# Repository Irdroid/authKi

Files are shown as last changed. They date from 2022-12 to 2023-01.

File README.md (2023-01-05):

# Open Source Crypto Authentication USB Dongle
<p align="center" width="55%">
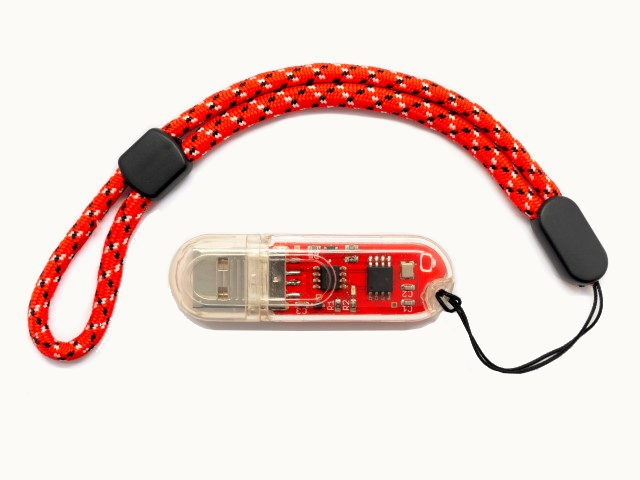
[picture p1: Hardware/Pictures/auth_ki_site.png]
     
</p>

Irdroid authKi is a Open Source crypto Authentication USB Dongle (Open source Hardware ID - BG000091), with built-in hardware support for Asymmetric Sign, Verify, Key Agreement for ECDSA - Elliptic curve digital signature algorithm, ECDH - Elliptic Curve Diffie-Hellman and NIST Standard P256 Elliptic Curve Support,  thanks to the built-in Cryptographic Co-Processor with Secure Hardware-Based Key Storage - ATECC608B by Microchip.

USB 2.0 Interface (and optional USB-C) to the host system with built-in drivers for GNU Linux. The authKi is targeted for use in GNU Linux, the ATECC608B crypto element inside the authKi can be accessed via libusb in MS Windows and Mac OS (Still work in progress). The device will show-up on the host system as a I2C sysfs entry, which is then used by the Microchip’s cryptoauthlib for communication with the authKi dongle.

## Hardware support for:

- Asymmetric Sign, Verify, Key Agreement:
- ECDSA: FIPS186-3 Elliptic Curve Digital Signature
- ECDH: FIPS SP800-56A Elliptic Curve Diffie-Hellman
- NIST Standard P256 Elliptic Curve Support

## Symmetric Algorithms:

- SHA-256 & HMAC Hash including off-chip context save/restore
- AES-128: Encrypt/Decrypt, Galois Field Multiply for GCM

## Networking Key Management Support:

- Turnkey PRF/HKDF calculation for TLS 1.2 & 1.3
- Ephemeral key generation and key agreement in SRAM
- Small message encryption with keys entirely protected

## Software Support:

- Microchip’s Cryptoauthlib ( provides API and examples for interfacing with the authKi
- Eclet - a commandline tool to sign verify export public keys
- Other examples in the Irdroid’s authKi Github repository

## Example use:

- SSH authentication with a remote system via ECDSA keypairs ( your private key never leaves the hardware secure element e.g the AuthKi)
- ECDSA elliptic curve authentication with git / GitHub ( your private key never leaves the hardware secure element e.g the AuthKi)
- Digital Signature and Verification of files via Ellliptic Curve Algorithms (ECDSA/ECDSH)
- Developing Secure Crypto Wallets for Bitcoin / Ethereum
- Experimenting with the Microchip’s Cryptoauthlib for interfacing with the device.

## Where to start?

### 1. Clone this repository: 
```javascript
git clone --recurse-submodules https://github.com/Irdroid/authKi.git
```
This will checkout the repo and all submodules. You can then compile and install the cryptoauthlib library localted in /Software/Cryptoauthlib/
**You can also download a pre-built release package from the "releases" section above**.
    
### 2.  Install OpenSC:
```javascript
sudo apt install opensc
```
Check if the sysfs /dev/i2c-x entry for the device is created (After you plug the authKi to your system issue dmesg, and see if the /dev/i2c-x is assigned), if not then you may need to issue:

```
sudo modprobe i2c-dev
```
The above will load the kernel module for i2c dev sysfs

### 4. Set **udev rules** 
(If you are compiling from source | **You can skip this step if you are installing a prebuilt cryptoauthlib package from the releases section above**), so that the authKi will always get the same i2c interface number as a sysfs entry 
    - Create a file in /etc/udev/rules.d/11-tiny.rules with the content : 
```javascript 
   ACTION=="add|change", SUBSYSTEM=="i2c-dev", ATTRS{idVendor}=="0403", ATTRS{idProduct}=="c631", SYMLINK+="i2c-20"
```
### 5. Create / Edit /var/lib/cryptoauthlib/0.conf
Add the following content ( If you are compiling / installing from source)
```javascript 

# Reserved Configuration for a device
# The objects in this file will be created and marked as undeletable
# These are processed in order. Configuration parameters must be comma
# delimited and may not contain spaces

# Set a label for this slot (optional) - will default to <slot>ABC so
# 0.conf will have a default label 00ABC
label = 00ABC

# Configure the device interface for an enabled HAL
# hid,i2c,<address>
# i2c,<address>,<bus>
# spi,<select_line>,<baud>
interface = i2c,6C,20

# Configure the device type - base part number (optional)
device = ATECC608B-TFLXTLS

#Configure open slots for additional pkcs11 objects (optional)
#freeslots = 1,2,3
freeslots = 2,3,4,5
# Manually configure keys into device locations (slots/handles)

# Slot 0 is the primary private key
object = private,device,0
#object = private,device,0
# Slot 15 is a public key
#object = public,root,15
```
### 6. Configure SSH:
Edit /home/your_user/.ssh/config and add:
```javascript 
PKCS11Provider /usr/lib/libcryptoauth.so
```
The above will configure the cryptoauthlib as a PKCS11 Provider for All SSH connections. To configure the use of the library and the authki for specific connection add the following (for example for GitHub authentication in ./ssh/config)

```javascript 
Host github.com
 PKCS11Provider /usr/lib/libcryptoauth.so
 Port 22
 User youruser
```
This way if you have multipl authentication dongles, and/or smartcards you can specify which connection will use the relevant authentication key/smartcard

### 7. Export the ECDSA Public key from the authKi
```javascript
ssh-keygen -D /usr/lib/libcryptoauth.so
```
### 8. Use the authKi for SSH Authentication / Github GIT+SSH
The above command will print your public ECDSA key in the console, the key is suitable for usage in a remote server authorized_keys file or with Github
After putting the public key into a remote system , you can ssh into it, while your authKi is inserted in your computer.

### 9 Configuring authKi for use with the Eclet

1. Compile and install the Ecltet, the source is located in /Software/Eclet

#### random
```bash
eclet random
62F95589AC76855A8F9204C9C6B8B85F06E6477D17C3888266AEE8E1CBD65319
```
#### serial-num
```bash
eclet serial-num
0123XXXXXXXXXXXXEE
```
X's indicate the unique serial number.

#### get-pub
```bash
eclet get-pub
04EED1CB629CF87F8BF6419986F990B92EA3DFA14CDAF70EB3E8DA8F9C9504DBC5B040D6480E88F895E9E1D4477970329B060450C80E1816EFED7B0FA49868CAEB
```
One can get the public key at any time calling the command get-pub. In case the public key of a specific slot has to be called use the parameter -k.

```bash
eclet get-pub -k 0
04EED1CB629CF87F8BF6419986F990B92EA3DFA14CDAF70EB3E8DA8F9C9504DBC5B040D6480E88F895E9E1D4477970329B060450C80E1816EFED7B0FA49868CAEB
```

#### sign
```bash
eclet sign -f ChangeLog
3BAEB5705D8765B34B389F1768BAC783FCA786AB64A760D10DD133C86E5892A7A790E424C8E1540551C99FBE4F9F531B504A6004F08F3E0D4E42E96BBDE5C179
```

Performs an ECDSA signature. Data can be specified as a file with the `-f` option or passed via `stdin`. The data will be SHA256 hashed prior to signing. The result is the signature in the format: R + S.

#### verify
```bash
eclet verify -f ChangeLog --signature C650D1A30194AD68F60F40C321FB084F6177BEDAC74D0F0C276ED35B00249AC8CF3E96FB7AB14AA48223FBA2E5DD9BCAE232BF963755C42F8FD9BD77FC145D41 --public-key 049B4A517704E16F3C99C6973E29F882EAF840DCD125C725C9552148A74349EB77BECB37AA2DB8056BAF0E236F6DCFEC2C5A9A0F23CEFD8A9DC1F4693718E725D2
```

Verifies an ECDSA signature using the device. You specify the data (which will be SHA256 hashed), the signature (R+S), and the public key (0x04+X+Y). Returns a `0` exit code on success.

#### offline-verify-sign
```bash
eclet offline-verify-sign -f ChangeLog --signature C650D1A30194AD68F60F40C321FB084F6177BEDAC74D0F0C276ED35B00249AC8CF3E96FB7AB14AA48223FBA2E5DD9BCAE232BF963755C42F8FD9BD77FC145D41 --public-key 049B4A517704E16F3C99C6973E29F882EAF840DCD125C725C9552148A74349EB77BECB37AA2DB8056BAF0E236F6DCFEC2C5A9A0F23CEFD8A9DC1F4693718E725D2
```
#### 10. There are other examples in the cryptoauthlib directory for other functionalities such as AES128 enclode/decode, SHA-256 tests and examples and more. 

### authKi unit's are available for purchase from Tindie - Click on the Tindie Logo below to see product details and pricing
<p align="center" width="30%">
<a href="https://www.tindie.com/products/irdroid/authki-crypto-authentication-dongle/">authKi ot Tindie</a>
</p>

The authKi repository and and the authKi website were pushed to GitHub, by using the Irdroid's authKi ECDSA Keypair

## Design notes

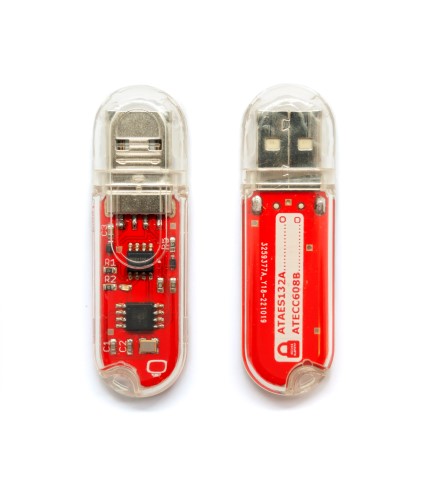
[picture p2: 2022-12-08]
Hardware/Pictures/PB170094-1-3 (Small).jpg

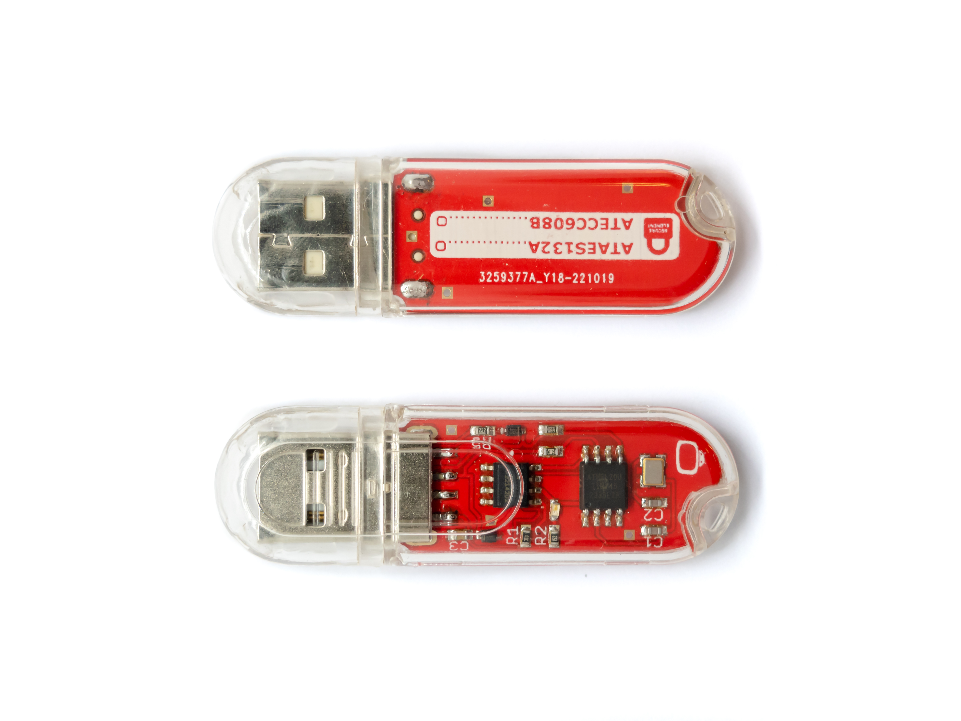
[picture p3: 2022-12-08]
Hardware/Pictures/Hi-Res/PB170094-3.jpg

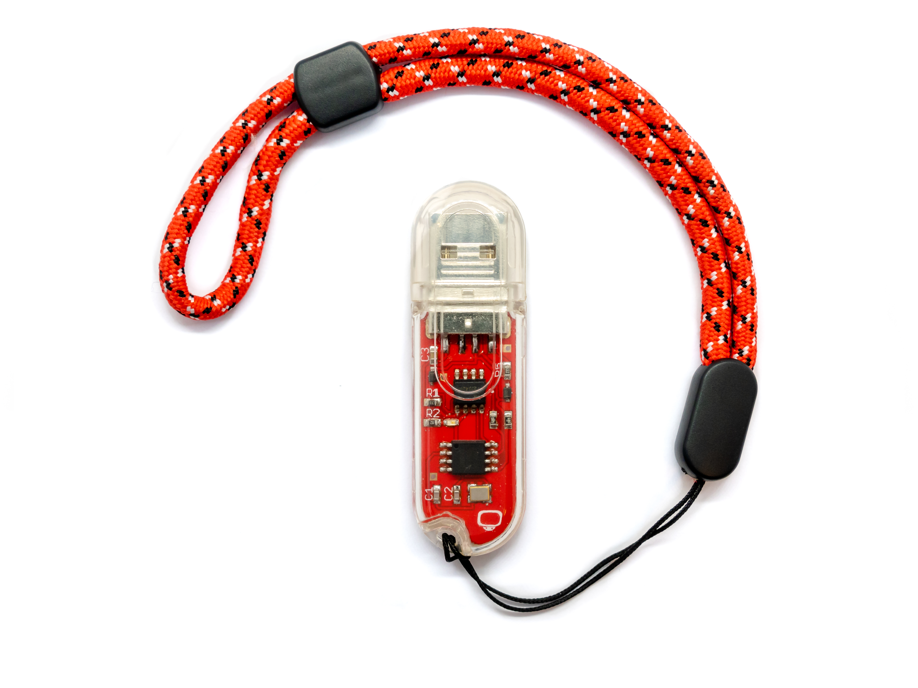
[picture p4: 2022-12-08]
Hardware/Pictures/Hi-Res/PB170083-2.jpg

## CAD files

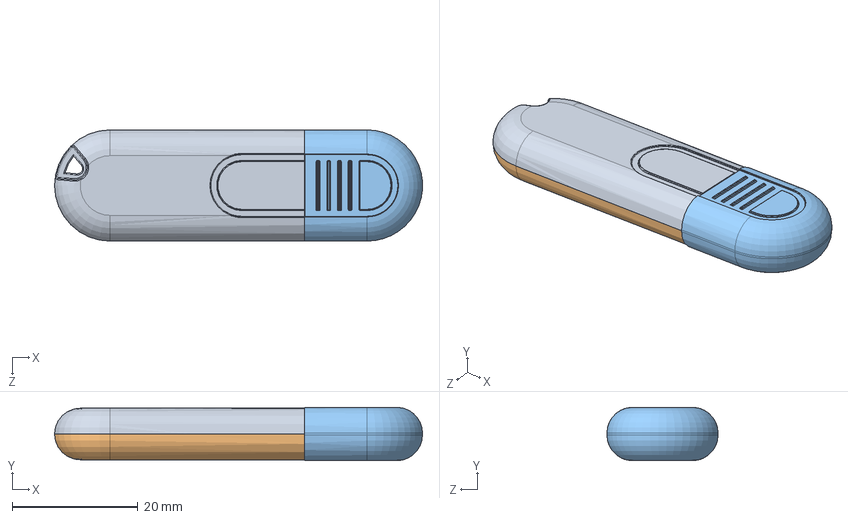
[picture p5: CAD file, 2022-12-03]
Hardware/Enclosure/3D Model/Сборка корпуса.SLDASM
58.6 x 8.50 x 17.7 mm
Верх
Низ
Колпачек

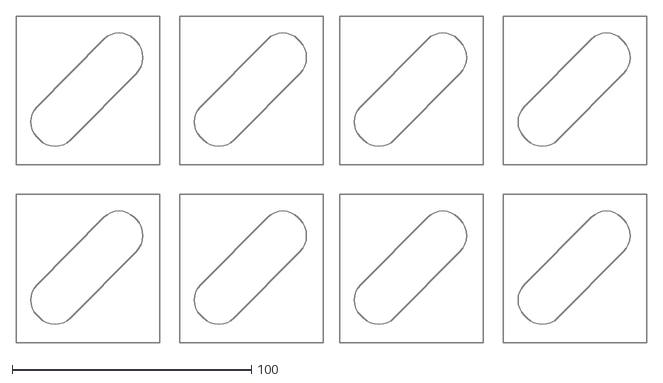
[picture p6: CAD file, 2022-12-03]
Hardware/Packing Box/DXF/boxpouter_grouped_with_opening.dxf
263.6 x 136.4

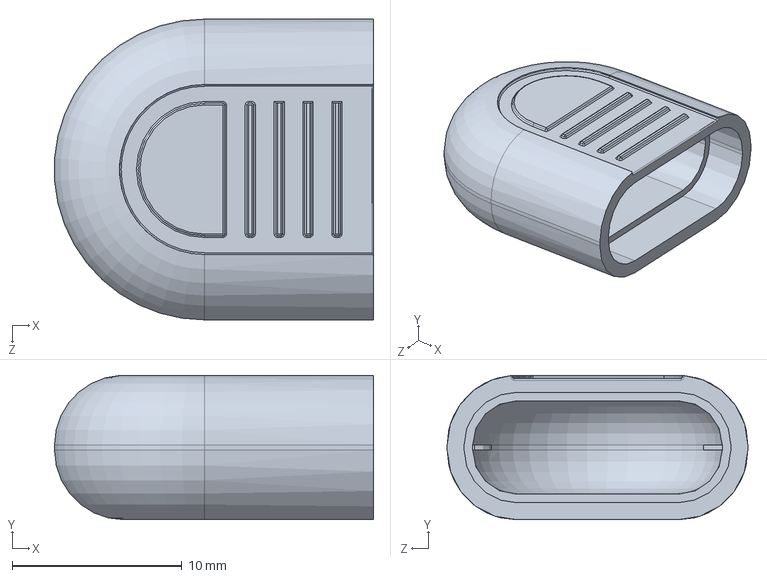
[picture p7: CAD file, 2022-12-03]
Hardware/Enclosure/3D Model/Колпачек.SLDPRT
18.8 x 8.50 x 17.7 mm

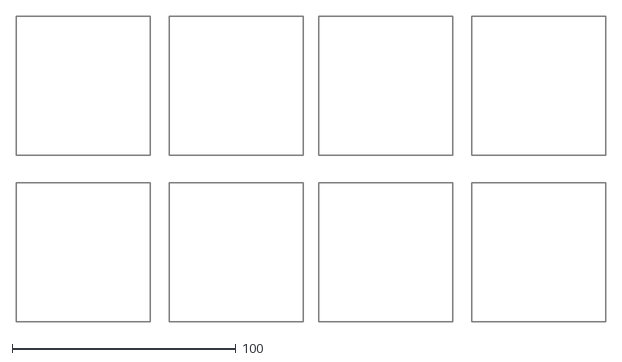
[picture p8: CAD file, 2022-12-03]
Hardware/Packing Box/DXF/boxpouter_grouped.dxf
263.6 x 136.4

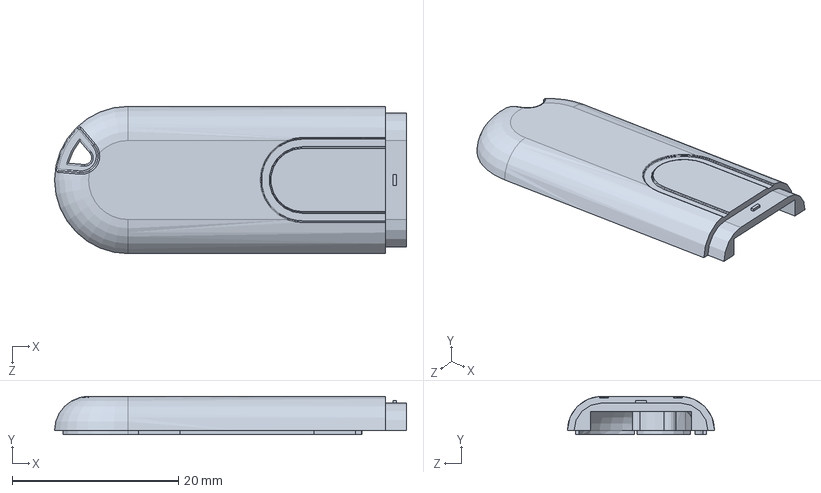
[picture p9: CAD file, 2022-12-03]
Hardware/Enclosure/3D Model/Верх.SLDPRT
42.3 x 4.60 x 17.7 mm

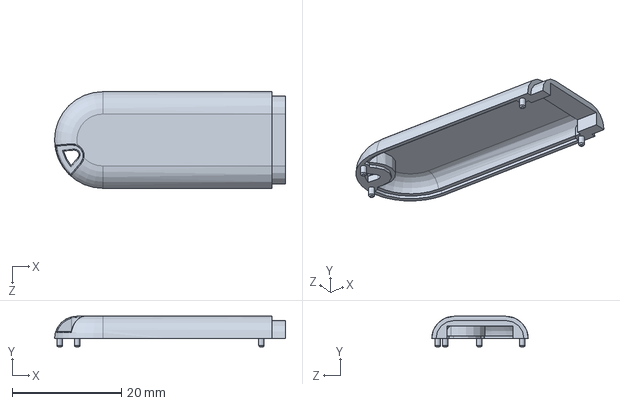
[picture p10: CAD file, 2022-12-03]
Hardware/Enclosure/3D Model/Низ.SLDPRT
42.3 x 5.60 x 17.7 mm

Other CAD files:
Hardware/Enclosure/3D Model/small plastic instrument enclosure usb stick junction housing abs material pcb enclosure.STEP

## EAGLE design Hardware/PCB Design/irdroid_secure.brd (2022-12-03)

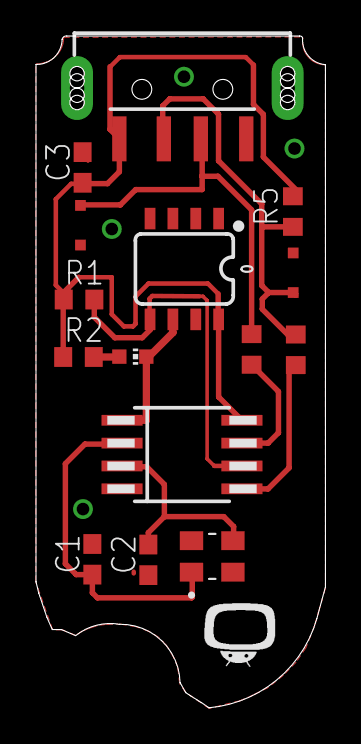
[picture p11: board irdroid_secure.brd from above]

Board: 2 copper layers, 16.1 x 37.3 mm, 16 parts (0 on the bottom side), 11 nets.

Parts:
0: Crypto; SO08
C1, C2, C3: C0603
D1, D2: SOD323-R
J1: USB_A_SMT_MALE; USB-A-SMT-MALE
LED1: CHIP-LED0603
MC: ATTINY45V-10S; SOIC8_EIAJ_208MIL
R1, R2, R3, R4, R5: R0603
U$2: IRDROIDLOGO
Y1: ABM8-16.000MHZ-B2-T; XTAL_ABM8-16.000MHZ-B2-T

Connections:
GND: 0.4, C1.2, C2.1, C3.2, D1.A, D2.A, J1.GND1, J1.SHLD1, J1.SHLD2, MC.4, Y1.2, Y1.4
unnamed: C1.1, MC.2, Y1.1
unnamed: C2.2, MC.3, Y1.3
unnamed: 0.5, MC.6, R1.2
unnamed: 0.6, LED1.C, MC.1
unnamed: MC.5, R3.2
unnamed: MC.7, R4.2
unnamed: D2.C, J1.D-1, R3.1, R5.1
unnamed: LED1.A, R2.2
unnamed: D1.C, J1.D+1, R4.1
VCC: 0.8, C3.1, J1.VBUS1, MC.8, R1.1, R2.1, R5.2

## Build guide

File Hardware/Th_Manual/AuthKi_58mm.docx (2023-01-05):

Start Here:

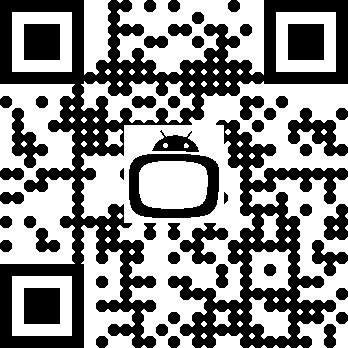
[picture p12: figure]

https://github.com/irdroid/authKi

AuthKi is Open source software and open source hardware, more information at:

https://certification.oshwa.org/bg000091.html

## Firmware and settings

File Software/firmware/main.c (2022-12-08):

/* Name: main.c
 * Project: i2c-tiny-usb
 * Author: Till Harbaum
 * Tabsize: 4
 * Copyright: (c) 2005 by Till Harbaum <till@harbaum.org>
 * License: GPL
 * This Revision: $Id: main.c,v 1.9 2007/06/07 13:53:47 harbaum Exp $
 *
 * $Log: main.c,v $
 * Revision 1.9  2007/06/07 13:53:47  harbaum
 * Version number fixes
 *
 * Revision 1.8  2007/05/19 12:30:11  harbaum
 * Updated USB stacks
 *
 * Revision 1.7  2007/04/22 10:34:05  harbaum
 * *** empty log message ***
 *
 * Revision 1.6  2007/01/05 19:30:58  harbaum
 * i2c clock bug fix
 *
 * Revision 1.5  2007/01/03 18:35:07  harbaum
 * usbtiny fixes and pcb layouts
 *
 * Revision 1.4  2006/12/03 21:28:59  harbaum
 * *** empty log message ***
 *
 * Revision 1.3  2006/11/22 19:12:45  harbaum
 * Added usbtiny support
 *
 * Revision 1.2  2006/11/14 19:15:13  harbaum
 * *** empty log message ***
 *
 */

#include <stdio.h>
#include <ctype.h>
#include <string.h>

#include <avr/io.h>
#include <avr/interrupt.h>
#include <avr/pgmspace.h>
#include <avr/wdt.h>

#include <util/delay.h>

#ifndef USBTINY
// use avrusb library
#include "usbdrv.h"
#include "oddebug.h"
#else
// use usbtiny library 
#include "usb.h"
#include "usbtiny.h"
typedef byte_t uchar;

#if! defined (__AVR_ATtiny45__)
#define USBDDR DDRC
#define USB_CFG_IOPORT PORTC
#else
#define USBDDR DDRB
#define USB_CFG_IOPORT PORTB
#endif

#define USB_CFG_DMINUS_BIT USBTINY_DMINUS
#define USB_CFG_DPLUS_BIT USBTINY_DPLUS

#define usbInit()  usb_init()
#define usbPoll()  usb_poll()
#endif

#define ENABLE_SCL_EXPAND

/* commands from USB, must e.g. match command ids in kernel driver */
#define CMD_ECHO       0
#define CMD_GET_FUNC   1
#define CMD_SET_DELAY  2
#define CMD_GET_STATUS 3

#define CMD_I2C_IO     4
#define CMD_I2C_BEGIN  1  // flag fo I2C_IO
#define CMD_I2C_END    2  // flag fo I2C_IO

/* linux kernel flags */
#define I2C_M_TEN		0x10	/* we have a ten bit chip address */
#define I2C_M_RD		0x01
#define I2C_M_NOSTART		0x4000
#define I2C_M_REV_DIR_ADDR	0x2000
#define I2C_M_IGNORE_NAK	0x1000
#define I2C_M_NO_RD_ACK		0x0800

/* To determine what functionality is present */
#define I2C_FUNC_I2C			0x00000001
#define I2C_FUNC_10BIT_ADDR		0x00000002
#define I2C_FUNC_PROTOCOL_MANGLING	0x00000004 /* I2C_M_{REV_DIR_ADDR,NOSTART,..} */
#define I2C_FUNC_SMBUS_HWPEC_CALC	0x00000008 /* SMBus 2.0 */
#define I2C_FUNC_SMBUS_READ_WORD_DATA_PEC  0x00000800 /* SMBus 2.0 */ 
#define I2C_FUNC_SMBUS_WRITE_WORD_DATA_PEC 0x00001000 /* SMBus 2.0 */ 
#define I2C_FUNC_SMBUS_PROC_CALL_PEC	0x00002000 /* SMBus 2.0 */
#define I2C_FUNC_SMBUS_BLOCK_PROC_CALL_PEC 0x00004000 /* SMBus 2.0 */
#define I2C_FUNC_SMBUS_BLOCK_PROC_CALL	0x00008000 /* SMBus 2.0 */
#define I2C_FUNC_SMBUS_QUICK		0x00010000 
#define I2C_FUNC_SMBUS_READ_BYTE	0x00020000 
#define I2C_FUNC_SMBUS_WRITE_BYTE	0x00040000 
#define I2C_FUNC_SMBUS_READ_BYTE_DATA	0x00080000 
#define I2C_FUNC_SMBUS_WRITE_BYTE_DATA	0x00100000 
#define I2C_FUNC_SMBUS_READ_WORD_DATA	0x00200000 
#define I2C_FUNC_SMBUS_WRITE_WORD_DATA	0x00400000 
#define I2C_FUNC_SMBUS_PROC_CALL	0x00800000 
#define I2C_FUNC_SMBUS_READ_BLOCK_DATA	0x01000000 
#define I2C_FUNC_SMBUS_WRITE_BLOCK_DATA 0x02000000 
#define I2C_FUNC_SMBUS_READ_I2C_BLOCK	0x04000000 /* I2C-like block xfer  */
#define I2C_FUNC_SMBUS_WRITE_I2C_BLOCK	0x08000000 /* w/ 1-byte reg. addr. */
#define I2C_FUNC_SMBUS_READ_I2C_BLOCK_2	 0x10000000 /* I2C-like block xfer  */
#define I2C_FUNC_SMBUS_WRITE_I2C_BLOCK_2 0x20000000 /* w/ 2-byte reg. addr. */
#define I2C_FUNC_SMBUS_READ_BLOCK_DATA_PEC  0x40000000 /* SMBus 2.0 */
#define I2C_FUNC_SMBUS_WRITE_BLOCK_DATA_PEC 0x80000000 /* SMBus 2.0 */

#define I2C_FUNC_SMBUS_BYTE I2C_FUNC_SMBUS_READ_BYTE | \
                            I2C_FUNC_SMBUS_WRITE_BYTE
#define I2C_FUNC_SMBUS_BYTE_DATA I2C_FUNC_SMBUS_READ_BYTE_DATA | \
                                 I2C_FUNC_SMBUS_WRITE_BYTE_DATA
#define I2C_FUNC_SMBUS_WORD_DATA I2C_FUNC_SMBUS_READ_WORD_DATA | \
                                 I2C_FUNC_SMBUS_WRITE_WORD_DATA
#define I2C_FUNC_SMBUS_BLOCK_DATA I2C_FUNC_SMBUS_READ_BLOCK_DATA | \
                                  I2C_FUNC_SMBUS_WRITE_BLOCK_DATA
#define I2C_FUNC_SMBUS_I2C_BLOCK I2C_FUNC_SMBUS_READ_I2C_BLOCK | \
                                  I2C_FUNC_SMBUS_WRITE_I2C_BLOCK

#define I2C_FUNC_SMBUS_EMUL I2C_FUNC_SMBUS_QUICK | \
                            I2C_FUNC_SMBUS_BYTE | \
                            I2C_FUNC_SMBUS_BYTE_DATA | \
                            I2C_FUNC_SMBUS_WORD_DATA | \
                            I2C_FUNC_SMBUS_PROC_CALL | \
                            I2C_FUNC_SMBUS_WRITE_BLOCK_DATA | \
                            I2C_FUNC_SMBUS_WRITE_BLOCK_DATA_PEC | \
                            I2C_FUNC_SMBUS_I2C_BLOCK

/* the currently support capability is quite limited */
const unsigned long func PROGMEM = I2C_FUNC_I2C | I2C_FUNC_SMBUS_EMUL;

#ifdef DEBUG
#define DEBUGF(format, args...) printf_P(PSTR(format), ##args)

/* ------------------------------------------------------------------------- */
static int uart_putchar(char c, FILE *stream) {
  if (c == '\n')
    uart_putchar('\r', stream);
  loop_until_bit_is_set(UCSRA, UDRE);
  UDR = c;
  return 0;
}

static FILE mystdout = FDEV_SETUP_STREAM(uart_putchar, NULL,
                                         _FDEV_SETUP_WRITE);
#else
#define DEBUGF(format, args...)
#endif

/* ------------------------------------------------------------------------- */
#define DEFAULT_DELAY 10  // default 10us (100khz)
static unsigned short clock_delay  = DEFAULT_DELAY;
static unsigned short clock_delay2 = DEFAULT_DELAY/2;

static unsigned short expected;
static unsigned char saved_cmd;

#if! defined (__AVR_ATtiny45__)
#define I2C_PORT   PORTC
#define I2C_PIN    PINC
#define I2C_DDR    DDRC
#define I2C_SDA    _BV(4)
#define I2C_SCL    _BV(5)
#else
#define I2C_PORT   PORTB
#define I2C_PIN    PINB
#define I2C_DDR    DDRB
#define I2C_SDA    _BV(1)
#define I2C_SCL    _BV(5)
#endif

static void i2c_io_set_sda(uchar hi) {
  if(hi) {
    I2C_DDR  &= ~I2C_SDA;    // high -> input
    I2C_PORT |=  I2C_SDA;    // with pullup
  } else {
    I2C_DDR  |=  I2C_SDA;    // low -> output
    I2C_PORT &= ~I2C_SDA;    // drive low
  }
}

static uchar i2c_io_get_sda(void) {
  return(I2C_PIN & I2C_SDA);
}

static void i2c_io_set_scl(uchar hi) {
#ifdef ENABLE_SCL_EXPAND
  _delay_loop_2(clock_delay2);
  if(hi) {
    I2C_DDR &= ~I2C_SCL;          // port is input
    I2C_PORT |= I2C_SCL;          // enable pullup

    // wait while pin is pulled low by client
    while(!(I2C_PIN & I2C_SCL));
  } else {
    I2C_DDR |= I2C_SCL;           // port is output
    I2C_PORT &= ~I2C_SCL;         // drive it low
  }
  _delay_loop_2(clock_delay);
#else
  _delay_loop_2(clock_delay2);
  if(hi) I2C_PORT |=  I2C_SCL;    // port is high
  else   I2C_PORT &= ~I2C_SCL;    // port is low
  _delay_loop_2(clock_delay);
#endif
}

static void i2c_init(void) {
  /* init the sda/scl pins */
  I2C_DDR &= ~I2C_SDA;            // port is input
  I2C_PORT |= I2C_SDA;            // enable pullup
#ifdef ENABLE_SCL_EXPAND
  I2C_DDR &= ~I2C_SCL;            // port is input
  I2C_PORT |= I2C_SCL;            // enable pullup
#else
  I2C_DDR |= I2C_SCL;             // port is output
#endif

  /* no bytes to be expected */
  expected = 0;
}

/* clock HI, delay, then LO */
static void i2c_scl_toggle(void) {
  i2c_io_set_scl(1);
  i2c_io_set_scl(0);
}

/* i2c start condition */
static void i2c_start(void) {
  i2c_io_set_sda(0);
  i2c_io_set_scl(0);
}

/* i2c repeated start condition */
static void i2c_repstart(void) 
{
  /* scl, sda may not be high */
  i2c_io_set_sda(1);
  i2c_io_set_scl(1);
  
  i2c_io_set_sda(0);
  i2c_io_set_scl(0);
}

/* i2c stop condition */
void i2c_stop(void) {
  i2c_io_set_sda(0);
  i2c_io_set_scl(1);
  i2c_io_set_sda(1);
}

uchar i2c_put_u08(uchar b) {
  char i;

  for (i=7;i>=0;i--) {
    if ( b & (1<<i) )  i2c_io_set_sda(1);
    else               i2c_io_set_sda(0);
    
    i2c_scl_toggle();           // clock HI, delay, then LO
  }
  
  i2c_io_set_sda(1);            // leave SDL HI
  i2c_io_set_scl(1);            // clock back up

  b = i2c_io_get_sda();         // get the ACK bit
  i2c_io_set_scl(0);            // not really ??

  return(b == 0);               // return ACK value
}

uchar i2c_get_u08(uchar last) {
  char i;
  uchar c,b = 0;

  i2c_io_set_sda(1);            // make sure pullups are activated
  i2c_io_set_scl(0);            // clock LOW

  for(i=7;i>=0;i--) {
    i2c_io_set_scl(1);          // clock HI
    c = i2c_io_get_sda();
    b <<= 1;
    if(c) b |= 1;
    i2c_io_set_scl(0);          // clock LO
  }

  if(last) i2c_io_set_sda(1);   // set NAK
  else     i2c_io_set_sda(0);   // set ACK

  i2c_scl_toggle();             // clock pulse
  i2c_io_set_sda(1);            // leave with SDL HI

  return b;                     // return received byte
}

#ifdef DEBUG
void i2c_scan(void) {
  uchar i = 0;

  for(i=0;i<127;i++) {
    i2c_start();                  // do start transition
    if(i2c_put_u08(i << 1))       // send DEVICE address
      DEBUGF("I2C device at address 0x%x\n", i);

    i2c_stop();
  }
}
#endif

/* ------------------------------------------------------------------------- */

struct i2c_cmd {
  unsigned char type;
  unsigned char cmd;
  unsigned short flags;
  unsigned short addr;
  unsigned short len;  
};

#define STATUS_IDLE          0
#define STATUS_ADDRESS_ACK   1
#define STATUS_ADDRESS_NAK   2

static uchar status = STATUS_IDLE;

static uchar i2c_do(struct i2c_cmd *cmd) {
  uchar addr;

  DEBUGF("i2c %s at 0x%02x, len = %d\n", 
	   (cmd->flags&I2C_M_RD)?"rd":"wr", cmd->addr, cmd->len); 

  /* normal 7bit address */
  addr = ( cmd->addr << 1 );
  if (cmd->flags & I2C_M_RD )
    addr |= 1;

  if(cmd->cmd & CMD_I2C_BEGIN) 
    i2c_start();
  else 
    i2c_repstart();    

  // send DEVICE address
  if(!i2c_put_u08(addr)) {
    DEBUGF("I2C read: address error @ %x\n", addr);

    status = STATUS_ADDRESS_NAK;
    expected = 0;
    i2c_stop();
  } else {  
    status = STATUS_ADDRESS_ACK;
    expected = cmd->len;
    saved_cmd = cmd->cmd;

    /* check if transfer is already done (or failed) */
    if((cmd->cmd & CMD_I2C_END) && !expected) 
      i2c_stop();
  }

  /* more data to be expected? */
#ifndef USBTINY
  return(cmd->len?0xff:0x00);
#else
  return(((cmd->flags & I2C_M_RD) && cmd->len)?0xff:0x00);
#endif
}

#ifndef USBTINY
uchar	usbFunctionSetup(uchar data[8]) {
  static uchar replyBuf[4];
  usbMsgPtr = replyBuf;
#else
extern	byte_t	usb_setup ( byte_t data[8] )
{
  byte_t *replyBuf = data;
#endif

  DEBUGF("Setup %x %x %x %x\n", data[0], data[1], data[2], data[3]);

  switch(data[1]) {

  case CMD_ECHO: // echo (for transfer reliability testing)
    replyBuf[0] = data[2];
    replyBuf[1] = data[3];
    return 2;
    break;

  case CMD_GET_FUNC:
    memcpy_P(replyBuf, &func, sizeof(func));
    return sizeof(func);
    break;

  case CMD_SET_DELAY:
    /* The delay function used delays 4 system ticks per cycle. */
    /* This gives 1/3us at 12Mhz per cycle. The delay function is */
    /* called twice per clock edge and thus four times per full cycle. */ 
    /* Thus it is called one time per edge with the full delay */ 
    /* value and one time with the half one. Resulting in */
    /* 2 * n * 1/3 + 2 * 1/2 n * 1/3 = n us. */
    clock_delay = *(unsigned short*)(data+2);
    if(!clock_delay) clock_delay = 1;
    clock_delay2 = clock_delay/2;
    if(!clock_delay2) clock_delay2 = 1;

    DEBUGF("request for delay %dus\n", clock_delay); 
    break;

  case CMD_I2C_IO:
  case CMD_I2C_IO + CMD_I2C_BEGIN:
  case CMD_I2C_IO                 + CMD_I2C_END:
  case CMD_I2C_IO + CMD_I2C_BEGIN + CMD_I2C_END:
    // these are only allowed as class transfers

    return i2c_do((struct i2c_cmd*)data);
    break;

  case CMD_GET_STATUS:
    replyBuf[0] = status;
    return 1;
    break;

  default:
    // must not happen ...
    break;
  }

  return 0;  // reply len
}


/*---------------------------------------------------------------------------*/
/* usbFunctionRead                                                           */
/*---------------------------------------------------------------------------*/

#ifndef USBTINY
uchar usbFunctionRead( uchar *data, uchar len )
#else
extern	byte_t	usb_in ( byte_t* data, byte_t len )
#endif
{
  uchar i;

  DEBUGF("read %d bytes, %d exp\n", len, expected);

  if(status == STATUS_ADDRESS_ACK) {
    if(len > expected) {
      DEBUGF("exceeds!\n");
      len = expected;
    }

    // consume bytes
    for(i=0;i<len;i++) {
      expected--;
      *data = i2c_get_u08(expected == 0);
      DEBUGF("data = %x\n", *data);
      data++;
    }

    // end transfer on last byte
    if((saved_cmd & CMD_I2C_END) && !expected) 
      i2c_stop();

  } else {
    DEBUGF("not in ack state\n");
    memset(data, 0, len);
  }
  return len;
}

/*---------------------------------------------------------------------------*/
/* usbFunctionWrite                                                          */
/*---------------------------------------------------------------------------*/

#ifndef USBTINY
uchar usbFunctionWrite( uchar *data, uchar len )
#else
extern	void	usb_out ( byte_t* data, byte_t len )
#endif
{
  uchar i, err=0;

  DEBUGF("write %d bytes, %d exp\n", len, expected);

  if(status == STATUS_ADDRESS_ACK) {
    if(len > expected) {
      DEBUGF("exceeds!\n");
      len = expected;
    }

    // consume bytes
    for(i=0;i<len;i++) {
      expected--;
      DEBUGF("data = %x\n", *data);
      if(!i2c_put_u08(*data++))
	err = 1;
    }

    // end transfer on last byte
    if((saved_cmd & CMD_I2C_END) && !expected) 
      i2c_stop();

    if(err) {
      DEBUGF("write failed\n");
      //TODO: set status
    }

  } else {
    DEBUGF("not in ack state\n");
    memset(data, 0, len);
  }

#ifndef USBTINY
  return len;
#endif
}


/* ------------------------------------------------------------------------- */

int	main(void) {
  wdt_enable(WDTO_1S);

#if DEBUG_LEVEL > 0
  /* let debug routines init the uart if they want to */
  odDebugInit();
#else
#ifdef DEBUG
  /* quick'n dirty uart init */
  UCSRB |= _BV(TXEN);
  UBRRL = F_CPU / (19200 * 16L) - 1;
#endif
#endif

#ifdef DEBUG
  stdout = &mystdout;
#endif

  DEBUGF("i2c-tiny-usb - (c) 2006 by Till Harbaum\n");

  i2c_init();

#ifdef DEBUG
  i2c_scan();
#endif

  /* clear usb ports */
  USB_CFG_IOPORT   &= (uchar)~((1<<USB_CFG_DMINUS_BIT)|(1<<USB_CFG_DPLUS_BIT));

  /* make usb data lines outputs */
  USBDDR    |= ((1<<USB_CFG_DMINUS_BIT)|(1<<USB_CFG_DPLUS_BIT));

  /* USB Reset by device only required on Watchdog Reset */
  _delay_loop_2(40000);   // 10ms

  /* make usb data lines inputs */
  USBDDR &= ~((1<<USB_CFG_DMINUS_BIT)|(1<<USB_CFG_DPLUS_BIT));

  usbInit();

  sei();
  for(;;) {	/* main event loop */
    wdt_reset();
    usbPoll();
  }

  return 0;
}

/* ------------------------------------------------------------------------- */

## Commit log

2022-12-03 Initial commit
    Hardware, PCB Design, packaging, enclosure
    [boxpouter_grouped.dxf, boxpouter_grouped_with_opening.dxf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]
2022-12-08 Moved top and bottom case holders into a directory
2023-01-05 Added OSHW Branding materials
    Added Open Source Hardware Branding materials

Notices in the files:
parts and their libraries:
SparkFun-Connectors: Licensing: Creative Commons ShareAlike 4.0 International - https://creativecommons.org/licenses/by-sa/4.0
